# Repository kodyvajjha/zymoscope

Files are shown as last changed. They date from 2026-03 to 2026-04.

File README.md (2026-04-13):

# Zymoscope

An ESP32-based fermentation monitoring and control system with a real-time web dashboard.

## Overview

<p align="center">
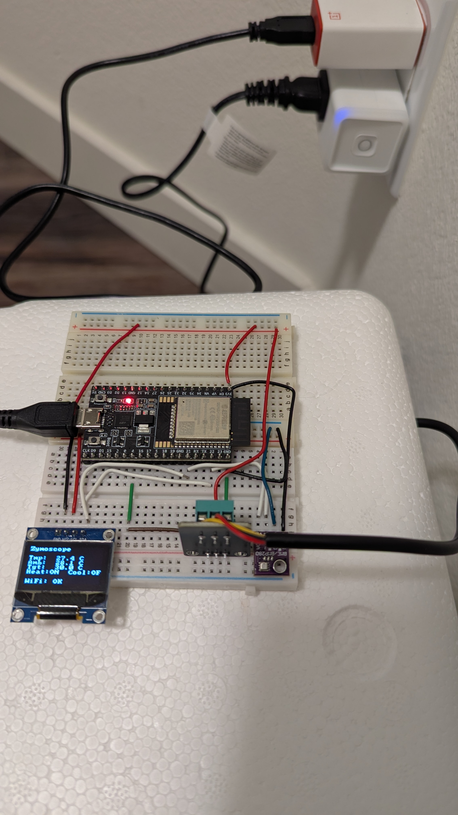
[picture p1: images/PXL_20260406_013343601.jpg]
Zymoscope prototype
  
  <br>
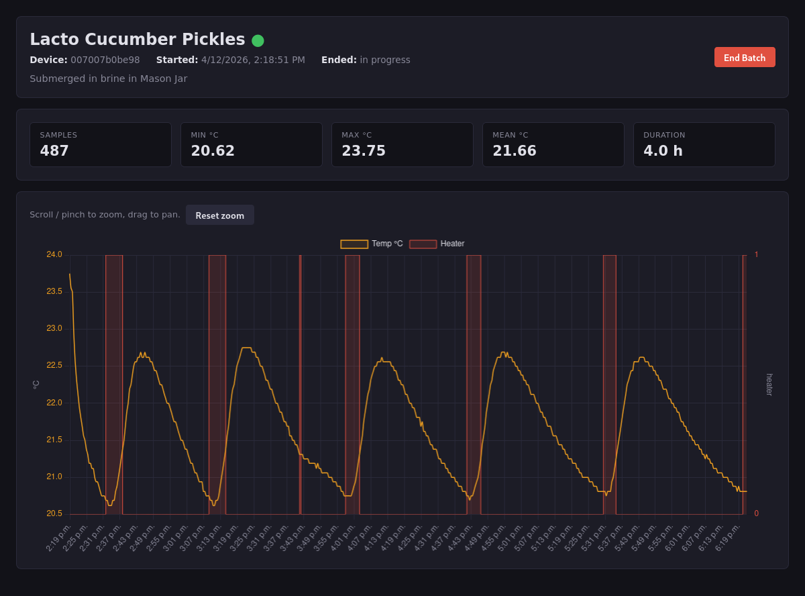
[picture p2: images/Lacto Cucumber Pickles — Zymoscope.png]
Dashboard screenshot — lacto cucumber pickles batch
  
</p>

Zymoscope monitors and controls fermentation environments using:

- **Temperature** sensing and PID control (DS18B20 probe + Kasa smart plug for heating/cooling)
- **Ambient climate** logging (BME280 — temperature, humidity, pressure)
- **Local display** on a 128x64 OLED for at-a-glance status
- **Wi-Fi telemetry** via MQTT to a self-hosted FastAPI + SQLite web dashboard
- **NVS-persisted setpoint** — the target temperature survives reboots; no dashboard needed to maintain control
- **Modular architecture** — ESP32 sensor nodes now, Raspberry Pi + camera later

Inspired by the [OpenAg FermentaBot](https://github.com/OpenAgricultureFoundation/fermentabot),
rebuilt from scratch with custom hardware, real sensor drivers, and a modern web frontend.

## What Can You Ferment With This?

Anything where temperature control and monitoring matter:

- **Koji** — *Aspergillus oryzae* needs 28–32 °C and high humidity for 40–48 hours.
  The PID holds your incubation chamber steady, the BME280 tracks humidity.
- **Natto** — *Bacillus subtilis* ferments at 38–42 °C for 22–24 hours.
  Tight temperature control is critical; even a few degrees off produces slimy,
  under-fermented beans.
- **Tempeh** — *Rhizopus oligosporus* sporulates at 30–32 °C over 24–48 hours.
  Too hot and the mold dies; too cold and it stalls. The dashboard shows you
  exactly when mycelium heat generation kicks in.
- **Beer / Cider / Mead** — ale yeast (18–22 °C), lager yeast (8–14 °C), or
  wild/mixed fermentation.
- **Kombucha** — SCOBY ferments best at 24–28 °C. Track progress over 7–14 days.
- **Hot Sauce** — lacto-fermented peppers at 20–24 °C.
- **Sauerkraut / Kimchi** — lacto-fermentation at 18–22 °C.
- **Yogurt / Kefir** — hold milk at 40–45 °C (yogurt) or 20–25 °C (kefir).
  The PID + smart plug keeps a heating pad at the right temperature overnight.
- **Bread / Sourdough** — proof at a controlled 24–28 °C. Bulk fermentation
  and final proof both benefit from consistent temperature.

The PID controller works with a seedling heat mat (via smart plug) for heating
and a small fan or mini fridge for cooling. One sensor node per vessel; run
multiple nodes reporting to the same dashboard.

## Architecture

```
ESP32 Sensor Node (per vessel)        Web App (laptop / Pi / server)
┌────────────────────────────┐        ┌─────────────────────────────┐
│ DS18B20 (1-Wire probe)     │  MQTT  │ FastAPI backend             │
│ BME280 (ambient)           │───────>│ SQLite storage              │
│ SSD1306 OLED (status)      │        │ WebSocket live push         │
│ PID temperature control    │<───────│ Chart.js dashboard          │
│ Kasa smart plug (via MQTT) │  cmds  │ Kasa plug control           │
└────────────────────────────┘        └─────────────────────────────┘
```

## Repository Layout

```
zymoscope/
├── firmware/                   # ESP-IDF v5.x firmware (C)
│   ├── main/
│   │   ├── app_main.c          # Entry point, FreeRTOS tasks
│   │   ├── sensor/
│   │   │   ├── ds18b20.c/h     # 1-Wire bit-bang, CRC-8, critical sections
│   │   │   ├── hx711.c/h       # 24-bit ADC bit-bang (optional)
│   │   │   └── bme280_i2c.c/h  # I2C driver, Bosch compensation formulas
│   │   ├── display/
│   │   │   └── oled.c/h        # SSD1306 128×64, built-in 8×8 font
│   │   ├── control/
│   │   │   └── pid.c/h         # PID with anti-windup, [-1,1] output
│   │   └── comms/
│   │       ├── wifi_sta.c/h    # Wi-Fi STA, auto-reconnect
│   │       └── mqtt_client.c/h # JSON telemetry + setpoint commands
│   ├── CMakeLists.txt
│   └── sdkconfig.defaults
├── dashboard/                  # Python web app
│   ├── zymoscope/
│   │   ├── server.py           # FastAPI routes + WebSocket
│   │   ├── db.py               # SQLite schema + queries (async)
│   │   ├── mqtt_sub.py         # MQTT subscriber thread
│   │   ├── smart_plug.py       # Kasa plug control + energy monitoring
│   │   └── config.py           # Environment-based settings
│   ├── templates/
│   │   └── index.html          # Dark-themed SPA, Chart.js live graphs
│   ├── mosquitto/
│   │   └── mosquitto.conf      # Local Mosquitto config
│   ├── docker-compose.yml      # Optional: Mosquitto + InfluxDB + Grafana
│   └── requirements.txt
├── hardware/                   # KiCad schematic + BOM
│   ├── zymoscope.kicad_pro
│   ├── zymoscope.kicad_sch
│   └── bom/
│       └── zymoscope-bom.csv
├── docs/
│   ├── design.md               # Full architecture + design rationale
│   ├── prototype-bom.md        # Ordering guide + wiring diagram
│   └── getting-started.md      # Step-by-step: order → build → ferment
├── .gitignore
├── LICENSE                     # GPL-3.0
└── README.md
```

## Prototype Build (~$40–55)

No custom PCB needed. Use an ESP32 dev board + breakout modules on a breadboard.

### Order from Mouser / DigiKey (~$20)

| Part | Mouser PN | Qty | ~Price |
|---|---|-----|---|
| ESP32-DevKitC-32E | 356-ESP32DEVKITC32E | 1 | $10.00 |
| DS18B20 waterproof stainless steel probe | 485-381 | 1 | $10.00 |
| 4.7 kΩ resistor (1/4W) | 603-MFR-25FBF52-4K7 | 1 | $0.10 |

### Order from Amazon (~$20–35)

| Part | Search Term | Qty | ~Price |
|---|---|-----|---|
| TP-Link Kasa KP115 smart plug | "TP-Link Kasa KP115" | 1 | $15–20 |
| BME280 I2C breakout | "BME280 breakout I2C" (NOT BMP280) | 1 | $3–5 |
| SSD1306 0.96" OLED 128×64 | "SSD1306 0.96 I2C OLED" | 1 | $3–4 |
| Half-size breadboard | "400 tie point breadboard" | 1 | $2–3 |
| Dupont jumper wires (M-M + M-F) | "dupont jumper wire kit" | 1 | $3–4 |
| Seedling heat mat | "seedling heat mat" | 1 | $8–12 |

### Optional extras

| Part | Search Term | Notes |
|---|---|---|
| HX711 + 5 kg load cell kit | "HX711 load cell kit 5kg" | For gravity estimation via weight loss |
| 2-ch 5V relay module | "2 channel 5V relay module" | For direct low-voltage DC control (fans, pumps) |

See [`docs/prototype-bom.md`](docs/prototype-bom.md) for detailed part notes and
[`docs/getting-started.md`](docs/getting-started.md) for the complete step-by-step
walkthrough from ordering parts to tracking your first fermentation.

## Quick Start

### Firmware

Requires [ESP-IDF v5.x](https://docs.espressif.com/projects/esp-idf/en/stable/esp32/get-started/).

```bash
# Set your Wi-Fi credentials
# Edit firmware/main/comms/wifi_sta.h: WIFI_SSID / WIFI_PASS

# Set your MQTT broker IP
# Edit firmware/main/app_main.c: MQTT_BROKER_URI

cd firmware/
source ~/esp/esp-idf/export.sh
idf.py set-target esp32
idf.py build
idf.py -p /dev/ttyUSB0 flash monitor
```

### MQTT Broker

```bash
# Install Mosquitto (Arch Linux)
sudo pacman -S mosquitto

# Run directly with the included config
mosquitto -c dashboard/mosquitto/mosquitto.conf
```

### Web Dashboard

```bash
cd dashboard/
pip install -r requirements.txt

# Set the Kasa plug IP (find with: kasa discover)
export KASA_HEATER_HOST=192.168.1.50

python -m zymoscope.server
# Open http://localhost:8000
```

The dashboard shows per-device cards with live temperature, ambient conditions,
plug states, and 24-hour trend charts. Use the "Target Temperature" control in
the sidebar to change the PID setpoint. Data persists in SQLite.

### Set Target Temperature

From the dashboard sidebar, or via curl:

```bash
curl -X POST http://localhost:8000/api/cmd/YOUR_DEVICE_ID \
  -H "Content-Type: application/json" \
  -d '{"setpoint": 25.0}'
```

The setpoint is saved to the ESP32's NVS flash — it persists across reboots
and works even without the dashboard running.

### Docker Stack (optional)

If you want Mosquitto + InfluxDB + Grafana alongside the web app:

```bash
cd dashboard/
cp .env.example .env   # edit secrets
docker compose up -d
```

## Wiring

```
ESP32 Pin     Peripheral
─────────     ──────────────────────────────────────────
GPIO 4        DS18B20 DATA + 4.7 kΩ pull-up to 3.3V
GPIO 21       I2C SDA (BME280 @ 0x76 + OLED @ 0x3C)
GPIO 22       I2C SCL (BME280 + OLED)
3.3V          DS18B20 VCC, BME280 VCC, OLED VCC
GND           Common ground
```

**Optional (if using HX711 / relay instead of smart plug):**

```
GPIO 18       HX711 SCK
GPIO 19       HX711 DOUT
GPIO 25       Relay IN1 (heater)
GPIO 26       Relay IN2 (cooler)
5V (VIN)      Relay module VCC, HX711 VCC
```

## OLED Display

```
Zymoscope

Tmp:  24.9 C      ← DS18B20 probe (-- if disconnected)
Amb:  22.3 C      ← BME280 ambient
Tgt:  20.0 C      ← PID setpoint
Heat:OFF Cool:OFF ← Kasa plug / relay state

WiFi: OK
```

## MQTT Topics

```
zymoscope/<mac>/telemetry    # JSON, published every 30 s
zymoscope/<mac>/cmd          # Subscribe: {"setpoint": 20.0}
zymoscope/<mac>/status       # LWT: "online" / "offline"
```

## Roadmap

- [x] ESP32 sensor node firmware (DS18B20, BME280, OLED, PID, MQTT)
- [x] FastAPI web dashboard with live charts
- [x] Kasa smart plug integration (heater/cooler control + energy monitoring)
- [x] NVS-persisted setpoint (survives reboots)
- [x] Critical sections for reliable 1-Wire reads on noisy power rails
- [ ] Raspberry Pi integration + camera module (krausen tracking)
- [ ] pH probe support (analog front-end)
- [ ] OTA firmware updates
- [ ] Fermentation profile automation (diacetyl rest, crash cool)
- [ ] Custom 2-layer PCB (KiCad, JLCPCB-ready)
- [ ] 3D-printable enclosure (OpenSCAD)

## License

This project is licensed under the **GNU General Public License v3.0**.
See [LICENSE](LICENSE) for details.

Hardware design files are additionally released under
**CERN Open Hardware Licence v2 – Strongly Reciprocal (CERN-OHL-S-2.0)**.

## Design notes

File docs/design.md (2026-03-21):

# Zymoscope — Design Document

## 1. Goals and Constraints

| Goal | Rationale |
|---|---|
| Self-hosted telemetry | No cloud dependency for reliability |
| ±0.1 °C temperature accuracy | Tight lager fermentation window |
| BLE tilt sensor support | Passive gravity readings without opening vessel |
| Sub-$30 BOM per unit | Hobbyist replicability |
| DIN-rail enclosure | Clean brewery panel mounting |

## 2. System Architecture

```
┌─────────────────────────────────────────────────────┐
│  Fermentation Vessel                                │
│  ┌──────────┐   ┌──────────┐   ┌────────────────┐  │
│  │ DS18B20  │   │  Tilt    │   │ CO2 pressure   │  │
│  │ (1-Wire) │   │ (BLE RX) │   │ sensor (I²C)   │  │
│  └────┬─────┘   └────┬─────┘   └───────┬────────┘  │
└───────┼──────────────┼─────────────────┼────────────┘
        │              │                 │
┌───────▼──────────────▼─────────────────▼────────────┐
│  Zymoscope PCB                                      │
│  ┌────────────────────────────────────────────────┐ │
│  │  ESP32-WROOM-32E                               │ │
│  │  ┌──────────┐  ┌──────────┐  ┌─────────────┐  │ │
│  │  │ 1-Wire   │  │  BLE     │  │  I²C master │  │ │
│  │  │ driver   │  │  scanner │  │             │  │ │
│  │  └────┬─────┘  └──────────┘  └──────┬──────┘  │ │
│  │       │   ┌─────────────────────────┘         │ │
│  │       └───►  Sensor fusion / state machine     │ │
│  │             │                                  │ │
│  │             ▼                                  │ │
│  │         MQTT publish ──► Wi-Fi ──► broker      │ │
│  │         OLED update                            │ │
│  │         Relay control (GPIO)                   │ │
│  └────────────────────────────────────────────────┘ │
│  ┌────────────┐  ┌───────────────────────────────┐  │
│  │ AMS1117    │  │ Relay ×2 (heater / cooler)    │  │
│  │ 3.3V LDO   │  │ 5V coil, opto-isolated        │  │
│  └────────────┘  └───────────────────────────────┘  │
└─────────────────────────────────────────────────────┘
                        │ MQTT
                        ▼
┌─────────────────────────────────────────────────────┐
│  Self-hosted stack (Raspberry Pi / VM)              │
│  Mosquitto ──► Telegraf ──► InfluxDB ──► Grafana    │
│                                 └──► Alert webhooks │
└─────────────────────────────────────────────────────┘
```

## 3. Hardware Design

### 3.1 MCU Selection — ESP32-WROOM-32E

- Dual-core Xtensa LX6 @ 240 MHz; plenty of headroom for BLE scanning + MQTT
- Integrated Wi-Fi (802.11 b/g/n) + BLE 4.2
- 4 MB flash; 520 KB SRAM
- Wide supply range (3.0–3.6 V); efficient at 80 MHz for always-on monitoring

### 3.2 Power Supply

- Input: 5 V DC barrel jack (2.1 mm center-positive)
- 3.3 V rail: AMS1117-3.3 LDO, 800 mA max
- Relay coils driven from 5 V rail directly (before LDO)
- ESP32 EN pin pulled high via 10 kΩ; boot strapping resistors per Espressif ref design

### 3.3 Temperature Sensing — DS18B20

- Parasitic power mode, 1-Wire on GPIO4
- 4.7 kΩ pull-up to 3.3 V
- 12-bit resolution → 0.0625 °C step; conversion time 750 ms max
- Up to 4 probes on one bus (vessel, ambient, cold side, hot side)

### 3.4 Display — SSD1306 128×64 OLED

- I²C at 0x3C, 400 kHz fast mode
- Shows: current temp, setpoint, gravity estimate, elapsed days, Wi-Fi status
- GPIO21 = SDA, GPIO22 = SCL

### 3.5 Relay Outputs

- Two SPDT relays, 10 A / 250 VAC contacts
- Opto-isolated driver (PC817); GPIO driven via NPN transistor (2N2222)
- Flyback diode on coil (1N4148)
- Output 1 — Heater (heating pad / heat wrap)
- Output 2 — Cooler (mini fridge or Peltier module)

### 3.6 Connectors

| Connector | Type | Signals |
|---|---|---|
| J1 | 2-pin 5.08 mm screw terminal | 5 V in, GND |
| J2 | 3-pin 3.81 mm screw terminal | 1-Wire (DATA, GND, VCC) |
| J3 | 2-pin 5.08 mm screw terminal | Relay 1 NO/COM |
| J4 | 2-pin 5.08 mm screw terminal | Relay 2 NO/COM |
| J5 | 4-pin 2.54 mm header | UART0 (TX, RX, GND, 3V3) for flashing |

## 4. Firmware Architecture

```
main/
├── app_main.c          Entry point, task creation
├── sensor/
│   ├── ds18b20.c       1-Wire driver
│   └── tilt_ble.c      BLE passive scanner (iBeacon / Tilt UUID)
├── control/
│   └── pid.c           Simple PID for temperature setpoint
├── comms/
│   ├── mqtt_client.c   Publish telemetry JSON
│   └── wifi_sta.c      Wi-Fi init + reconnect
├── display/
│   └── oled.c          SSD1306 I²C driver + layout
└── config/
    └── nvs_config.c    Persist setpoint + credentials to NVS
```

### 4.1 MQTT Topic Schema

```
zymoscope/<device_id>/telemetry   JSON, published every 30 s
zymoscope/<device_id>/cmd         Subscribe for setpoint / relay override
zymoscope/<device_id>/status      LWT "offline" / "online"
```

Telemetry payload example:
```json
{
  "ts": 1710000000,
  "temp_c": [20.1, 19.8],
  "gravity_sg": 1.048,
  "relay": [0, 1],
  "rssi": -62,
  "uptime_s": 86400
}
```

## 5. Dashboard Stack

| Service | Image | Port |
|---|---|---|
| Mosquitto | eclipse-mosquitto:2 | 1883, 8883 |
| Telegraf | telegraf:1.30 | — |
| InfluxDB | influxdb:2.7 | 8086 |
| Grafana | grafana/grafana-oss:10.4 | 3000 |

Grafana dashboards are provisioned via YAML in `dashboard/grafana/provisioning/`.

## 6. Open Items / Future Work

- [ ] Add flow meter for sparge water (v3)
- [ ] OTA firmware update via HTTPS
- [ ] PCB revision: add TVS diodes on relay output terminals
- [ ] Evaluate CO2 volume measurement via pressure + temp logging
- [ ] Mobile-friendly Grafana layout

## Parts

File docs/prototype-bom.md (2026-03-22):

# Zymoscope v2 — Prototype Build Guide

## Overview

This is the **minimum viable prototype**: an ESP32 dev board + breakout sensor
modules wired on a protoboard. No custom PCB needed. Total cost: **~$45–55** (or ~$60–75 with an optional Kasa smart plug)
depending on supplier.

The goal is to validate the sensor pipeline, firmware, and web app before
committing to a PCB revision.

---

## Parts List

### Core (order from Mouser or DigiKey)

| # | Part | Mouser PN | Qty | ~Price | Notes |
|---|---|---|-----|---|---|
| 1 | **ESP32-DevKitC-32E** | 356-ESP32DEVKITC32E | 1 | $10.00 | USB-C variant preferred. Any ESP32 dev board with GPIO breakout works. |
| 2 | **DS18B20 waterproof stainless steel probe** (1m cable) | 485-381 | 1 | $10.00 | Pre-wired stainless steel probe — required for liquid immersion. |
| 3 | **4.7 kΩ resistor** (1/4W axial) | 603-MFR-25FBF52-4K7 | 1 | $0.10 | 1-Wire pull-up. Grab a 5-pack. |
| 4 | **10 kΩ resistor** (1/4W axial) | 603-MFR-25FBF52-10K | 2 | $0.10 | Pull-ups. Grab a 5-pack. |

**Mouser subtotal: ~$20**

### Breakout Modules (cheaper on Amazon or AliExpress)

These are commodity breakout boards. Mouser sells some of them but at 3–5x the
price. Amazon 2-day shipping is the sweet spot for prototyping.

| # | Part | Where to Buy | Qty | ~Price | Notes |
|---|---|---|-----|---|---|
| 5 | **HX711 + 5 kg load cell kit** | Amazon / AliExpress | 1 | $8–10 | Search "HX711 load cell kit 5kg". Comes with the HX711 breakout board + aluminum bar load cell + wires. This is your gravity sensor. |
| 6 | **BME280 breakout** (I2C, 3.3V) | Amazon / AliExpress | 1 | $3–5 | Search "BME280 breakout I2C". **Make sure it's a BME280, not BMP280** — the BME has humidity. 4-pin (VCC, GND, SCL, SDA). |
| 7 | **SSD1306 0.96" OLED** (I2C, 128×64) | Amazon / AliExpress | 1 | $3–4 | Search "SSD1306 0.96 I2C OLED". 4-pin version (VCC, GND, SCL, SDA). White or blue, doesn't matter. |
| 8 | **2-channel 5V relay module** (opto-isolated) | Amazon | 1 | $4–5 | Search "2 channel 5V relay module optocoupler". Has screw terminals for AC loads. High/low trigger selectable. |
| 9 | **Half-size breadboard** (400 tie points) | Amazon | 1 | $2–3 | Or a 7×9 cm solderable protoboard if you want something permanent. |
| 10 | **Dupont jumper wires** (M-M, M-F) | Amazon | 1 pack | $3–4 | 40-pin ribbon, get both male-male and male-female. |
| 11 | **Micro USB or USB-C cable** | — | 1 | $0 | You probably have one. Powers the ESP32 + provides serial for flashing. |

### Optional: Smart Plug (recommended for heater/cooler control)

| # | Part | Where to Buy | Qty | ~Price | Notes |
|---|---|---|-----|---|---|
| 12 | **TP-Link Kasa KP115** smart plug | Amazon | 1 | $15–20 | Search "TP-Link Kasa KP115". Has energy monitoring (power, voltage, current). Controlled locally via python-kasa — no cloud required. Plug your seedling heat mat or space heater into this instead of wiring mains through the relay module. KP125, HS110, or similar Kasa plugs also work. |

**Amazon subtotal: ~$25–30** (or ~$40–50 with smart plug)

---

## What You Probably Already Have

- A laptop with USB (for flashing firmware)
- A 5V USB power supply / phone charger (1A+ is fine for prototyping)
- Something to ferment (beer, kombucha, whatever — or just a jar of warm water to test with)

## What You Do NOT Need Yet

- Custom PCB (that's phase 2, after we validate the prototype)
- Raspberry Pi (the web app runs on your laptop for now)
- pH sensor (adds analog complexity — save for v2.1)
- Barrel jack / DIN rail enclosure (prototype lives on the bench)
- Pi Camera (future phase)

---

## Wiring Guide

Once parts arrive, wire it up like this:

```
ESP32 DevKit Pin    →   Peripheral
──────────────────────────────────────────────────
GPIO 4              →   DS18B20 DATA (yellow wire)
                        + 4.7 kΩ pull-up to 3.3V
3.3V                →   DS18B20 VCC (red wire)
GND                 →   DS18B20 GND (black wire)

GPIO 18             →   HX711 SCK
GPIO 19             →   HX711 DT (DOUT)
3.3V                →   HX711 VCC
GND                 →   HX711 GND
                        Load cell wires → HX711 E+/E-/A+/A-
                        (red→E+, black→E-, white→A+, green→A-)

GPIO 21 (SDA)       →   BME280 SDA  +  OLED SDA  (shared I2C bus)
GPIO 22 (SCL)       →   BME280 SCL  +  OLED SCL  (shared I2C bus)
3.3V                →   BME280 VCC  +  OLED VCC
GND                 →   BME280 GND  +  OLED GND
                        (BME280 default addr: 0x76)
                        (SSD1306 default addr: 0x3C)

GPIO 25             →   Relay module IN1 (heater)
GPIO 26             →   Relay module IN2 (cooler)
5V (VIN pin)        →   Relay module VCC
GND                 →   Relay module GND
                        (Set relay jumper to LOW-trigger if available)
```

### Load Cell Mounting (for gravity estimation)

For prototyping, the simplest setup:

1. Screw the load cell to a flat board (wood or acrylic) at one end
2. Attach a small platform on the free end (zip-tie a flat piece)
3. Place your fermentation vessel on the platform
4. Tare after placing the full vessel — you're measuring *weight loss* from CO2 off-gassing

A 5 kg cell works for vessels up to ~5 kg total (≈1 gallon batch + container).
For 5-gallon batches, get a 20 kg load cell instead (~$2 more).

---

## Order Checklist

Copy-paste for ordering:

```
Mouser / DigiKey:
  [ ] ESP32-DevKitC-32E (or any ESP32 dev board)     ×1
  [ ] DS18B20 waterproof probe (pre-wired, 1m)        ×1
  [ ] 4.7 kΩ 1/4W resistor (5-pack)                   ×1
  [ ] 10 kΩ 1/4W resistor (5-pack)                     ×1

Amazon:
  [ ] HX711 + 5 kg load cell kit                       ×1
  [ ] BME280 I2C breakout (NOT BMP280)                  ×1
  [ ] SSD1306 0.96" OLED I2C 128×64                     ×1
  [ ] 2-channel 5V relay module (opto-isolated)         ×1
  [ ] Half-size breadboard (or 7×9 cm protoboard)       ×1
  [ ] Dupont jumper wires (M-M + M-F, 40-pin)          ×1

Optional:
  [ ] TP-Link Kasa KP115 smart plug (for heater)       ×1

Total: ~$45–55 (or ~$60–75 with smart plug)
```

---

## Next Steps After Parts Arrive

1. Wire everything per the diagram above
2. Flash the firmware: `cd firmware/ && idf.py build flash monitor`
3. Start the web app: `cd dashboard/ && python -m zymoscope.server`
4. Open `http://localhost:8080` — you should see live sensor data
5. Calibrate the load cell with a known weight
6. Stick the temp probe in your vessel and start a batch

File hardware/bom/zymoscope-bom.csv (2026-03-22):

Reference | Quantity | Value | Footprint | MPN | Supplier | Supplier PN | Unit Price (USD) | Notes
U1 | 1 | ESP32-WROOM-32E | RF_Module:ESP32-WROOM-32 | ESP32-WROOM-32E-N4 | Mouser | 356-ESP32WROOM32EN4 | 3.50 | 4 MB flash variant
U2 | 1 | AMS1117-3.3 | Package_TO_SOT_SMD:SOT-223-3_TabPin2 | AMS1117-3.3 | LCSC | C6186 | 0.15 | 800 mA LDO
U3 | 1 | SSD1306 OLED 128x64 | Connector_PinHeader_2.54mm:PinHeader_1x04_P2.54mm_Vertical | SSD1306 0.96" | AliExpress | — | 1.20 | I2C | 4-pin breakout
DS1 | 1 | DS18B20 | — | DS18B20+ | Mouser | 485-381 | 10.00 | Waterproof stainless steel probe (1m cable)
K1 | 1 | Relay 5V SPDT 10A | Relay_THT:Relay_SPDT_Omron_G5LE | G5LE-14-DC5 | Mouser | 653-G5LE-14DC5 | 1.85 | 5V coil
K2 | 1 | Relay 5V SPDT 10A | Relay_THT:Relay_SPDT_Omron_G5LE | G5LE-14-DC5 | Mouser | 653-G5LE-14DC5 | 1.85 | 5V coil
Q1 | 1 | 2N2222A | Package_TO_SOT_THT:TO-92_Inline | 2N2222A | Mouser | 512-2N2222A | 0.25 | Relay driver NPN (K1)
Q2 | 1 | 2N2222A | Package_TO_SOT_THT:TO-92_Inline | 2N2222A | Mouser | 512-2N2222A | 0.25 | Relay driver NPN (K2)
OC1 | 1 | PC817 | Package_DIP:DIP-4_W7.62mm | PC817C | LCSC | C66880 | 0.08 | Opto-isolator (K1 drive)
OC2 | 1 | PC817 | Package_DIP:DIP-4_W7.62mm | PC817C | LCSC | C66880 | 0.08 | Opto-isolator (K2 drive)
D1 | 1 | 1N4148 | Diode_THT:D_DO-35_SOD27_P7.62mm_Horizontal | 1N4148 | Mouser | 512-1N4148 | 0.05 | Flyback diode K1
D2 | 1 | 1N4148 | Diode_THT:D_DO-35_SOD27_P7.62mm_Horizontal | 1N4148 | Mouser | 512-1N4148 | 0.05 | Flyback diode K2
R1 | 1 | 4.7k | Resistor_THT:R_Axial_DIN0207_L6.3mm_D2.5mm_P10.16mm_Horizontal | — | — | — | 0.02 | 1-Wire pull-up
R2 | 1 | 10k | Resistor_THT:R_Axial_DIN0207_L6.3mm_D2.5mm_P10.16mm_Horizontal | — | — | — | 0.02 | ESP32 EN pull-up
R3 | 1 | 1k | Resistor_THT:R_Axial_DIN0207_L6.3mm_D2.5mm_P10.16mm_Horizontal | — | — | — | 0.02 | Q1 base resistor
R4 | 1 | 1k | Resistor_THT:R_Axial_DIN0207_L6.3mm_D2.5mm_P10.16mm_Horizontal | — | — | — | 0.02 | Q2 base resistor
R5 | 1 | 10k | Resistor_THT:R_Axial_DIN0207_L6.3mm_D2.5mm_P10.16mm_Horizontal | — | — | — | 0.02 | GPIO0 pull-up (boot)
C1 | 1 | 100nF | Capacitor_SMD:C_0402_1005Metric | — | — | — | 0.02 | 3.3V bypass (near U2)
C2 | 1 | 100nF | Capacitor_SMD:C_0402_1005Metric | — | — | — | 0.02 | 3.3V bypass (near U1)
C3 | 1 | 10uF 10V | Capacitor_THT:C_Radial_D5.0mm_H11.0mm_P2.00mm | — | — | — | 0.10 | 3.3V bulk
C4 | 1 | 100uF 10V | Capacitor_THT:C_Radial_D8.0mm_H11.5mm_P3.50mm | — | — | — | 0.15 | 5V bulk
J1 | 1 | Barrel Jack 2.1mm | Connector_BarrelJack:BarrelJack_Wuerth_6941xx301002 | — | Mouser | — | 0.80 | 5V DC input
J2 | 1 | Screw Terminal 3-pin 3.81mm | TerminalBlock_Phoenix:MKDS_1 | 5_3-5.08 | — | — | — | 0.60 | 1-Wire probe connector
J3 | 1 | Screw Terminal 2-pin 5.08mm | TerminalBlock_Phoenix:MKDS_1 | 5_2-5.08 | — | — | — | 0.45 | Relay 1 output
J4 | 1 | Screw Terminal 2-pin 5.08mm | TerminalBlock_Phoenix:MKDS_1 | 5_2-5.08 | — | — | — | 0.45 | Relay 2 output
J5 | 1 | Pin Header 4-pin 2.54mm | Connector_PinHeader_2.54mm:PinHeader_1x04_P2.54mm_Vertical | — | — | — | 0.20 | UART/prog header
PCB | 1 | Custom 2-layer PCB | — | — | JLCPCB | — | 8.00 | 10 pcs @ $8 min order
Enclosure | 1 | DIN rail enclosure | — | — | AliExpress | — | 4.50 | 45 mm DIN rail snap
 |  |  |  |  |  | Estimated total (1 unit): | $26.30

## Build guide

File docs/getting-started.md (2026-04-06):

# Zymoscope v2 — Getting Started (Step by Step)

Everything from ordering parts to watching your first fermentation curve on
the dashboard.

---

## Step 1: Order Parts

Place two orders. The Mouser/DigiKey parts are precision components with
exact part numbers. The Amazon parts are generic breakout boards — any
equivalent works.

### Mouser order (~$20, ships in 1–2 days)

Go to [mouser.com](https://www.mouser.com). Add each part number to your cart:

| Part | Mouser Part Number | Qty |
|---|---|-----|
| ESP32-DevKitC-32E dev board | **356-ESP32DEVKITC32E** | 1 |
| DS18B20 temperature probe | **485-381** | 1 |
| 4.7 kΩ resistor, 1/4W | **603-MFR-25FBF52-4K7** | 5 (pack) |

> **Note:** This is the waterproof stainless steel probe version with
> pre-wired leads (red/yellow/black). Required for liquid immersion.

### Amazon order (~$25–35, ships in 1–2 days with Prime)

Search for each item. These are commodity parts — any seller works.

| Part | What to Search | Qty | Tips |
|---|---|-----|---|
| TP-Link Kasa KP115 smart plug | "TP-Link Kasa KP115" | 1 | The KP115 includes energy monitoring (power/voltage/current shown on the dashboard). KP125 or HS110 also work. ~$15–20. |
| BME280 breakout | "BME280 breakout board I2C 3.3V" | 1 | **IMPORTANT: verify it says BME280, not BMP280.** The BMP lacks the humidity sensor. Should be a small purple or blue board with 4 pins (VCC, GND, SCL, SDA). **Solder the header pins** — resting the board on unsoldered pins causes noise that corrupts the DS18B20. |
| SSD1306 OLED | "SSD1306 0.96 inch OLED I2C 128x64" | 1 | 4-pin I2C version (not SPI). Color doesn't matter — white or blue. **Solder header pins.** |
| Seedling heat mat | "seedling heat mat" | 1 | Plugs into the Kasa smart plug. The PID controller turns it on/off to maintain target temperature. |
| Breadboard | "solderless breadboard 830 point" or "400 tie point breadboard" | 1 | Full-size (830 point) is easiest for the ESP32-DevKitC. Half-size works if you run power/ground off-board. |
| Jumper wires | "dupont jumper wire kit male male female" | 1 | 40-pin ribbon. Get a pack with both male-male and male-female wires. |

### What you probably already have

- USB-A to Micro USB or USB-C cable (for the ESP32)
- A laptop (Linux, macOS, or Windows — for flashing and running the dashboard)
- A 5V USB power supply or phone charger (1A+)

### Optional extras

| Part | What to Search | Notes |
|---|---|---|
| HX711 + 5 kg load cell kit | "HX711 load cell kit 5kg" | For gravity estimation via weight loss. Not needed for basic temperature control. |
| 2-channel relay module | "2 channel 5V relay module optocoupler" | For direct low-voltage DC control (fans, pumps, LED strips). Not needed if using the Kasa smart plug. |
| 10 kΩ resistor, 1/4W | 603-MFR-25FBF52-10K (Mouser) | Only needed if using the HX711. |

### Total: ~$40–55

---

## Step 2: Install Software (while you wait for parts)

### 2a: Install ESP-IDF (firmware toolchain)

Follow Espressif's official guide for your OS:
https://docs.espressif.com/projects/esp-idf/en/stable/esp32/get-started/

**Linux (quick version):**

```bash
sudo apt install git wget flex bison gperf python3 python3-venv \
  cmake ninja-build ccache libffi-dev libssl-dev dfu-util libusb-1.0-0

mkdir -p ~/esp
cd ~/esp
git clone --recursive https://github.com/espressif/esp-idf.git -b v5.2.2
cd esp-idf
./install.sh esp32
source export.sh    # run this in every new terminal, or add to .bashrc
```

**Arch Linux:**

```bash
sudo pacman -S git wget flex bison gperf python cmake ninja ccache \
  libffi openssl dfu-util libusb

mkdir -p ~/esp && cd ~/esp
git clone --recursive https://github.com/espressif/esp-idf.git -b v5.2.2
cd esp-idf
./install.sh esp32
source export.sh
```

**macOS:**

```bash
brew install cmake ninja dfu-util python3
mkdir -p ~/esp && cd ~/esp
git clone --recursive https://github.com/espressif/esp-idf.git -b v5.2.2
cd esp-idf
./install.sh esp32
source export.sh
```

Verify it works:

```bash
idf.py --version
# Should print something like: ESP-IDF v5.2.2
```

### 2b: Install Python dependencies (web dashboard)

```bash
cd /path/to/zymoscope/dashboard
python3 -m venv .venv
source .venv/bin/activate
pip install -r requirements.txt
```

### 2c: Install an MQTT broker

The web app and ESP32 communicate via MQTT. You need a broker running
somewhere on your network.

**Option A — Run directly (simplest):**

```bash
# Install
sudo pacman -S mosquitto          # Arch
sudo apt install mosquitto         # Debian/Ubuntu
brew install mosquitto             # macOS

# Run with the included config
mosquitto -c /path/to/zymoscope/dashboard/mosquitto/mosquitto.conf
```

**Option B — Docker:**

```bash
docker run -d --name mosquitto \
  -p 1883:1883 \
  eclipse-mosquitto:2 \
  mosquitto -c /mosquitto-no-auth.conf
```

**Option C — Use the included Docker Compose stack:**

```bash
cd dashboard/
cp .env.example .env
docker compose up -d mosquitto
```

Verify the broker is running:

```bash
# In one terminal:
mosquitto_sub -h localhost -t "test/#"

# In another:
mosquitto_pub -h localhost -t "test/hello" -m "it works"
# You should see "it works" appear in the first terminal
```

### 2d: Set up the Kasa smart plug

1. Plug in the KP115 and set it up on your Wi-Fi using the Kasa app (one-time)
2. Find its IP address:

```bash
kasa discover
```

Note the IP address — you'll need it when starting the dashboard.

---

## Step 3: Wire the Hardware

Unpack everything and set it up on the breadboard. Work through one
peripheral at a time — it's easier to debug that way.

> **Important:** Solder header pins onto the BME280 and OLED modules before
> wiring. Resting them on unsoldered pins causes intermittent contact that
> corrupts sensor readings and produces CRC errors.

### 3a: Place the ESP32 dev board

Straddle it across the center channel of the breadboard so the pins go
into both sides. The USB port should face outward for easy access.

### 3b: Wire the DS18B20 temperature probe

```
DS18B20 wire color    →   ESP32
──────────────────────────────────
Red (VCC)             →   3.3V
Black (GND)           →   GND
Yellow (DATA)         →   GPIO 4

Also: place the 4.7 kΩ resistor between GPIO 4 and 3.3V
      (this is the 1-Wire pull-up — required)
```

### 3c: Wire the BME280 (ambient sensor)

```
BME280 pin        →   ESP32
──────────────────────────────────
VCC               →   3.3V
GND               →   GND
SDA               →   GPIO 21
SCL               →   GPIO 22
```

> **Tip:** Run separate power jumpers from the ESP32 3.3V pin to each sensor
> rather than daisy-chaining them on one breadboard power rail. This reduces
> noise coupling between the BME280 and DS18B20.

### 3d: Wire the SSD1306 OLED

Shares the same I2C bus as the BME280 — wire to the same GPIO 21 / 22:

```
OLED pin          →   ESP32
──────────────────────────────────
VCC               →   3.3V
GND               →   GND
SDA               →   GPIO 21  (same wire row as BME280 SDA)
SCL               →   GPIO 22  (same wire row as BME280 SCL)
```

Both devices coexist on the same bus (BME280 @ address 0x76, OLED @ 0x3C).

### 3e: Set up the Kasa smart plug

1. Plug the seedling heat mat into the Kasa smart plug
2. Plug the smart plug into the wall outlet
3. The dashboard controls the plug over Wi-Fi — no wiring to the ESP32

### 3f: Double-check

Before powering on:

- [ ] All GND wires go to the same ground rail
- [ ] 3.3V is not shorted to anything it shouldn't be
- [ ] The 4.7 kΩ resistor is between GPIO 4 and 3.3V
- [ ] I2C SDA/SCL wires from BME280 and OLED both go to GPIO 21/22
- [ ] BME280 and OLED header pins are **soldered**, not just resting
- [ ] No loose jumper wires touching things they shouldn't

---

## Step 4: Configure and Flash the Firmware

### 4a: Set your Wi-Fi credentials

Edit `firmware/main/comms/wifi_sta.h` and change the defaults:

```c
#ifndef WIFI_SSID
#define WIFI_SSID "YourWiFiName"       // <── change this
#endif

#ifndef WIFI_PASS
#define WIFI_PASS "YourWiFiPassword"   // <── change this
#endif
```

### 4b: Set your MQTT broker address

Find the IP of the machine running Mosquitto:

```bash
# Linux
ip addr show | grep 'inet 10\.\|inet 192\.'

# macOS
ipconfig getifaddr en0
```

Edit `firmware/main/app_main.c` and change the broker URI:

```c
#ifndef MQTT_BROKER_URI
#define MQTT_BROKER_URI "mqtt://192.168.1.100:1883"  // <── your broker IP
#endif
```

### 4c: Build and flash

Plug the ESP32 into your laptop via USB.

```bash
# Make sure ESP-IDF is sourced
source ~/esp/esp-idf/export.sh

cd /path/to/zymoscope/firmware

idf.py set-target esp32
idf.py build
idf.py -p /dev/ttyUSB0 flash monitor
```

> **Port notes:**
> - Linux: usually `/dev/ttyUSB0` or `/dev/ttyACM0`
> - macOS: `/dev/cu.usbserial-*` or `/dev/cu.SLAB_USBtoUART`
> - If permission denied on Linux: `sudo usermod -aG dialout $USER` then log out/in

You should see log output like:

```
I (520) zymoscope: Zymoscope v2 starting...
I (530) zymoscope: Device MAC: AA:BB:CC:DD:EE:FF
I (845) wifi_sta: Connecting...
I (935) wifi:connected with YourWiFiName
I (875) bme280: BME280 initialised (addr=0x76, I2C port 0)
I (985) oled: SSD1306 128x64 OLED initialised (addr=0x3C)
I (1015) ds18b20: Found sensor 1: 2831A37B00000085
I (2655) mqtt: Connected to broker
```

The OLED should light up showing temperature, target setpoint, and connection
status. Press `Ctrl+]` to exit the serial monitor.

---

## Step 5: Start the Web Dashboard

### 5a: Start Mosquitto (if not already running)

```bash
mosquitto -c /path/to/zymoscope/dashboard/mosquitto/mosquitto.conf
```

### 5b: Start the dashboard

In a new terminal:

```bash
cd /path/to/zymoscope/dashboard
source .venv/bin/activate

# Set the Kasa plug IP
export KASA_HEATER_HOST=192.168.1.50    # your plug's IP from kasa discover

# Optional: for a cooler plug too
# export KASA_COOLER_HOST=192.168.1.51

python -m zymoscope.server
```

Open **http://localhost:8000** in your browser.

You should see:
- A dark-themed dashboard
- A card for your ESP32 device (identified by its MAC address)
- Live temperature and ambient readings
- Heater/cooler state indicators
- A line chart updating every 30 seconds
- "Target Temperature" control in the sidebar

If you don't see a device card, check:
1. Is the ESP32 connected to Wi-Fi? (check serial monitor output)
2. Is the MQTT broker running?
3. Is the ESP32's `MQTT_BROKER_URI` pointing to the right IP?

---

## Step 6: Set the Target Temperature

The PID controller maintains a target temperature by toggling the Kasa smart
plug (heater) on and off. The default is 20.0 °C.

### From the dashboard

Use the "Target Temperature" input in the sidebar. Enter a value and click
**Set**. The OLED will update to show the new target.

### From the command line

```bash
# Replace the device ID with yours (shown in serial monitor or dashboard)
curl -X POST http://localhost:8000/api/cmd/aabbccddeeff \
  -H "Content-Type: application/json" \
  -d '{"setpoint": 25.0}'
```

### Via MQTT directly

```bash
mosquitto_pub -h localhost \
  -t "zymoscope/aabbccddeeff/cmd" \
  -m '{"setpoint": 25.0}'
```

The setpoint is saved to the ESP32's NVS (non-volatile storage). It persists
across reboots — you can unplug the laptop and the ESP32 keeps controlling
temperature at the last setpoint.

---

## Step 7: Start a Fermentation

### 7a: Prepare your vessel

Whatever you're fermenting — beer, kombucha, cider, mead, hot sauce, etc.
A 1-gallon glass jug or a small fermentation bucket works well.

### 7b: Position the sensors

1. Dip the DS18B20 probe into the liquid (use the airlock hole or tape it
   to the outside of the vessel for external temp)
2. Place the seedling heat mat under or around the vessel, plugged into the
   Kasa smart plug
3. The BME280 stays on the breadboard — it reads ambient room conditions
4. The OLED sits on the breadboard — it shows live status

### 7c: Power on

1. Plug in the ESP32 via USB
2. Wait for the boot sequence
3. Check the serial monitor to confirm readings look sane
4. Check the web dashboard — you should see the device card with live data

### 7d: Walk away

The system now runs autonomously:

- Temperature is logged every 5 seconds
- Telemetry is published to MQTT every 30 seconds
- The PID controller toggles the heat mat via the Kasa plug to maintain
  your target temperature
- The web dashboard stores and plots everything (when running)
- The ESP32 + Kasa plug work independently of the dashboard

Check in on the dashboard periodically, or just glance at the OLED.

---

## Troubleshooting

| Problem | Check |
|---|---|
| ESP32 won't flash | Correct USB port? Try holding BOOT button while flashing. Run `ls /dev/tty*` to find the port. |
| No temperature readings | Is the 4.7 kΩ pull-up resistor in place? Check DS18B20 wire colors. |
| CRC mismatch errors | Solder the BME280/OLED header pins. Unsoldered pins cause noise on the shared power rail. Use separate 3.3V jumpers for each sensor. |
| OLED blank | Is it wired to GPIO 21/22? Check the I2C address — some OLEDs use 0x3D instead of 0x3C. Solder the pins. |
| BME280 reads 0.0 | Likely bad connection during init — solder pins, then reboot. Make sure it's a BME280, not BMP280. |
| Wi-Fi won't connect | Check SSID/password in wifi_sta.h. ESP32 only supports 2.4 GHz networks. |
| Dashboard shows no devices | Is Mosquitto running? Is the ESP32's MQTT_BROKER_URI correct? Check with `mosquitto_sub -t "zymoscope/#"`. |
| Kasa plug not found | Run `kasa discover`. Make sure the plug is on the same Wi-Fi network. Check KASA_HEATER_HOST env var. |
| Watchdog timer errors | Normal during early boot if many sensors are initializing. Should resolve after a few seconds. |
| MQTT keeps reconnecting | Check the Mosquitto log for "already connected" errors. Make sure only one client uses the same ID. |

---

## Optional: HX711 Load Cell (Gravity Estimation)

If you want to estimate specific gravity via weight loss during fermentation,
add the HX711 + load cell kit.

### Wiring

```
HX711 pin         →   ESP32
──────────────────────────────────
VCC               →   3.3V
GND               →   GND
SCK               →   GPIO 18
DT (DOUT)         →   GPIO 19
```

Load cell to HX711: Red→E+, Black→E-, White→A+, Green→A-.

### Calibration

1. Power on — the ESP32 auto-tares on boot
2. Place a known weight on the platform (e.g., 500 ml water = ~500 g)
3. Adjust `HX711_DEFAULT_SCALE` in `firmware/main/sensor/hx711.c` if needed

---

## Optional: Relay Module (Direct Control)

If you prefer direct low-voltage DC control (fans, pumps, LED strips) instead
of smart plugs:

### Wiring

```
Relay module pin  →   ESP32
──────────────────────────────────
VCC               →   5V (VIN pin on ESP32)
GND               →   GND
IN1               →   GPIO 25  (heater control)
IN2               →   GPIO 26  (cooler control)
```

> **Note:** The relay module VCC goes to **5V/VIN**, not 3.3V. Do not connect
> mains loads to the relay screw terminals unless you know what you're doing.
> For mains loads, use the Kasa smart plug instead.

---

## What's Next

Once your prototype is running and tracking a fermentation:

- **Add more DS18B20 probes** — the firmware supports up to 4 on the same bus.
  Just wire additional probes to the same GPIO 4 + 3.3V + GND lines.
- **Run it on a Pi** — move the dashboard to a Raspberry Pi with a small
  screen for a dedicated brewing station.
- **Add a camera** — a Pi Camera Module can track krausen height and color.
  This is the planned Phase 3.

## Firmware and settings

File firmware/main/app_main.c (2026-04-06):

/*
 * Zymoscope v2 — Main application
 *
 * Wires together all subsystems:
 *   - DS18B20 temperature sensors (1-Wire, GPIO 4)
 *   - HX711 load cell ADC (GPIO 18/19)
 *   - BME280 ambient temp/humidity/pressure (I2C 0x76)
 *   - SSD1306 OLED display (I2C 0x3C)
 *   - PID temperature controller driving relays (GPIO 25/26)
 *   - Wi-Fi STA with MQTT telemetry
 *
 * Three FreeRTOS tasks:
 *   sensor_task     — reads all sensors every 5 s, updates OLED
 *   control_task    — runs PID every 5 s, drives heat/cool relays
 *   telemetry_task  — publishes MQTT JSON every 30 s
 */

#include <math.h>
#include <string.h>
#include <stdio.h>

#include "freertos/FreeRTOS.h"
#include "freertos/task.h"
#include "freertos/semphr.h"
#include "driver/gpio.h"
#include "esp_log.h"
#include "esp_mac.h"
#include "nvs_flash.h"
#include "nvs.h"

#include "sensor/ds18b20.h"
#include "sensor/hx711.h"
#include "sensor/bme280_i2c.h"
#include "display/oled.h"
#include "control/pid.h"
#include "comms/wifi_sta.h"
#include "comms/mqtt_client.h"

static const char *TAG = "zymoscope";

/* ------------------------------------------------------------------ */
/*  Relay GPIOs                                                       */
/* ------------------------------------------------------------------ */
#define RELAY_HEAT_GPIO  25
#define RELAY_COOL_GPIO  26

/* ------------------------------------------------------------------ */
/*  Shared state (protected by mutex)                                 */
/* ------------------------------------------------------------------ */
static SemaphoreHandle_t state_mutex;

static struct {
    float temps[DS18B20_MAX_SENSORS];
    int   temp_count;
    float bme_temp;
    float bme_humidity;
    float bme_pressure;
    float weight_g;
    float gravity_est;
    int   relay_heat;
    int   relay_cool;
    float setpoint;
} shared;

/* ------------------------------------------------------------------ */
/*  MQTT broker URI (compile-time default)                            */
/* ------------------------------------------------------------------ */
#ifndef MQTT_BROKER_URI
#define MQTT_BROKER_URI "mqtt://192.168.1.100:1883"
#endif

/* ------------------------------------------------------------------ */
/*  PID defaults                                                      */
/* ------------------------------------------------------------------ */
#define PID_KP  2.0f
#define PID_KI  0.1f
#define PID_KD  0.5f
#define PID_DEFAULT_SETPOINT  20.0f   /* degrees C */

/* ------------------------------------------------------------------ */
/*  Crude specific-gravity estimator from weight loss                 */
/*  Uses the idea that CO2 mass loss tracks sugar consumption.        */
/*  OG is assumed 1.050; calibrate for your wort.                     */
/* ------------------------------------------------------------------ */
static float initial_weight = 0.0f;
#define ASSUMED_OG  1.050f

static float estimate_gravity(float current_weight)
{
    if (initial_weight <= 0.0f) return ASSUMED_OG;
    float loss = initial_weight - current_weight;
    if (loss < 0.0f) loss = 0.0f;
    /* Rough: 1 g CO2 lost ≈ 0.001 SG drop per litre.
       Adjust divisor for your batch volume. */
    float sg = ASSUMED_OG - (loss / 1000.0f) * 0.001f;
    if (sg < 0.990f) sg = 0.990f;
    return sg;
}

/* ------------------------------------------------------------------ */
/*  Relay helpers                                                     */
/* ------------------------------------------------------------------ */

static void relay_init(void)
{
    gpio_config_t io = {
        .pin_bit_mask = (1ULL << RELAY_HEAT_GPIO) | (1ULL << RELAY_COOL_GPIO),
        .mode         = GPIO_MODE_OUTPUT,
        .pull_up_en   = GPIO_PULLUP_DISABLE,
        .pull_down_en = GPIO_PULLDOWN_DISABLE,
        .intr_type    = GPIO_INTR_DISABLE,
    };
    gpio_config(&io);
    gpio_set_level(RELAY_HEAT_GPIO, 0);
    gpio_set_level(RELAY_COOL_GPIO, 0);
}

/* ------------------------------------------------------------------ */
/*  sensor_task — read all sensors every 5 s                          */
/* ------------------------------------------------------------------ */

static void sensor_task(void *arg)
{
    (void)arg;
    bool first_weight = true;

    for (;;) {
        float temps[DS18B20_MAX_SENSORS];
        int   temp_count = 0;
        float bme_t = 0, bme_h = 0, bme_p = 0;
        float weight = 0;

        /* DS18B20 — read first, before any I2C activity */
        if (ds18b20_read_temps(temps, &temp_count) == ESP_OK) {
            for (int i = 0; i < temp_count; i++) {
                ESP_LOGI(TAG, "DS18B20[%d]: %.2f C", i, temps[i]);
            }
        }

        /* Brief settling delay before I2C sensors to avoid power rail noise
           coupling into the 1-Wire bus during the last read's tail */
        vTaskDelay(pdMS_TO_TICKS(50));

        /* BME280 */
        if (bme280_read(&bme_t, &bme_h, &bme_p) == ESP_OK) {
            ESP_LOGI(TAG, "BME280: %.1f C, %.1f%% RH, %.1f hPa",
                     bme_t, bme_h, bme_p);
        }

        /* HX711 */
        if (hx711_get_grams(&weight) == ESP_OK) {
            ESP_LOGI(TAG, "Weight: %.1f g", weight);
            if (first_weight && weight > 100.0f) {
                initial_weight = weight;
                first_weight = false;
                ESP_LOGI(TAG, "Initial weight captured: %.1f g", initial_weight);
            }
        }

        float sg = estimate_gravity(weight);

        /* Update shared state */
        if (xSemaphoreTake(state_mutex, pdMS_TO_TICKS(100))) {
            memcpy(shared.temps, temps, sizeof(temps));
            shared.temp_count   = temp_count;
            shared.bme_temp     = bme_t;
            shared.bme_humidity = bme_h;
            shared.bme_pressure = bme_p;
            shared.weight_g     = weight;
            shared.gravity_est  = sg;
            xSemaphoreGive(state_mutex);
        }

        /* Update OLED */
        float display_temp = (temp_count > 0) ? temps[0] : NAN;
        float sp = PID_DEFAULT_SETPOINT;
        if (xSemaphoreTake(state_mutex, pdMS_TO_TICKS(100))) {
            sp = shared.setpoint;
            xSemaphoreGive(state_mutex);
        }
        oled_show_status(display_temp, bme_t, sp,
                         shared.relay_heat, shared.relay_cool,
                         wifi_sta_is_connected());

        vTaskDelay(pdMS_TO_TICKS(5000));
    }
}

/* ------------------------------------------------------------------ */
/*  control_task — PID temperature control every 5 s                  */
/* ------------------------------------------------------------------ */

static void control_task(void *arg)
{
    (void)arg;

    /* Load setpoint from NVS (persists across reboots) */
    float initial_sp = PID_DEFAULT_SETPOINT;
    {
        nvs_handle_t nvs;
        if (nvs_open("zymoscope", NVS_READONLY, &nvs) == ESP_OK) {
            uint32_t raw;
            if (nvs_get_u32(nvs, "setpoint", &raw) == ESP_OK) {
                memcpy(&initial_sp, &raw, sizeof(float));
                ESP_LOGI(TAG, "Loaded setpoint from NVS: %.1f C", initial_sp);
            }
            nvs_close(nvs);
        }
    }

    pid_ctrl_t pid;
    pid_init(&pid, PID_KP, PID_KI, PID_KD, initial_sp);

    if (xSemaphoreTake(state_mutex, pdMS_TO_TICKS(100))) {
        shared.setpoint = initial_sp;
        xSemaphoreGive(state_mutex);
    }

    for (;;) {
        /* Check for setpoint commands from MQTT */
        float new_sp = mqtt_get_cmd_setpoint();
        if (!isnan(new_sp)) {
            pid_set_setpoint(&pid, new_sp);
            ESP_LOGI(TAG, "PID setpoint changed to %.1f C", new_sp);

            /* Persist to NVS */
            nvs_handle_t nvs;
            if (nvs_open("zymoscope", NVS_READWRITE, &nvs) == ESP_OK) {
                uint32_t raw;
                memcpy(&raw, &new_sp, sizeof(float));
                nvs_set_u32(nvs, "setpoint", raw);
                nvs_commit(nvs);
                nvs_close(nvs);
            }

            if (xSemaphoreTake(state_mutex, pdMS_TO_TICKS(100))) {
                shared.setpoint = new_sp;
                xSemaphoreGive(state_mutex);
            }
        }

        /* Get current fermentation temperature */
        float temp = 0;
        if (xSemaphoreTake(state_mutex, pdMS_TO_TICKS(100))) {
            if (shared.temp_count > 0) {
                temp = shared.temps[0];
            } else {
                temp = shared.bme_temp;
            }
            xSemaphoreGive(state_mutex);
        }

        /* Run PID */
        float output = pid_update(&pid, temp);

        /* Drive relays:
         *   output > 0.1  → heat ON,  cool OFF
         *   output < -0.1 → heat OFF, cool ON
         *   otherwise     → both OFF (deadband)
         */
        int heat = 0, cool = 0;
        if (output > 0.1f) {
            heat = 1;
        } else if (output < -0.1f) {
            cool = 1;
        }

        gpio_set_level(RELAY_HEAT_GPIO, heat);
        gpio_set_level(RELAY_COOL_GPIO, cool);

        if (xSemaphoreTake(state_mutex, pdMS_TO_TICKS(100))) {
            shared.relay_heat = heat;
            shared.relay_cool = cool;
            xSemaphoreGive(state_mutex);
        }

        ESP_LOGD(TAG, "PID: temp=%.1f sp=%.1f out=%.2f heat=%d cool=%d",
                 temp, pid.setpoint, output, heat, cool);

        vTaskDelay(pdMS_TO_TICKS(5000));
    }
}

/* ------------------------------------------------------------------ */
/*  telemetry_task — MQTT publish every 30 s                          */
/* ------------------------------------------------------------------ */

static void telemetry_task(void *arg)
{
    (void)arg;

    for (;;) {
        vTaskDelay(pdMS_TO_TICKS(30000));

        if (!mqtt_is_connected()) {
            ESP_LOGW(TAG, "MQTT not connected, skipping telemetry");
            continue;
        }

        telemetry_t telem = {0};

        if (xSemaphoreTake(state_mutex, pdMS_TO_TICKS(100))) {
            memcpy(telem.temp_c, shared.temps, sizeof(shared.temps));
            telem.temp_count    = shared.temp_count;
            telem.humidity      = shared.bme_humidity;
            telem.pressure_hpa  = shared.bme_pressure;
            telem.weight_g      = shared.weight_g;
            telem.gravity_est   = shared.gravity_est;
            telem.relay1        = shared.relay_heat;
            telem.relay2        = shared.relay_cool;
            telem.wifi_connected = wifi_sta_is_connected();
            xSemaphoreGive(state_mutex);
        }

        esp_err_t err = mqtt_publish_telemetry(&telem);
        if (err == ESP_OK) {
            ESP_LOGI(TAG, "Telemetry published");
        } else {
            ESP_LOGW(TAG, "Telemetry publish failed: %s", esp_err_to_name(err));
        }
    }
}

/* ------------------------------------------------------------------ */
/*  app_main                                                          */
/* ------------------------------------------------------------------ */

void app_main(void)
{
    ESP_LOGI(TAG, "Zymoscope v2 starting...");

    /* Print device ID (MAC-based) */
    {
        uint8_t mac[6];
        esp_read_mac(mac, ESP_MAC_WIFI_STA);
        ESP_LOGI(TAG, "Device MAC: %02X:%02X:%02X:%02X:%02X:%02X",
                 mac[0], mac[1], mac[2], mac[3], mac[4], mac[5]);
    }

    /* Create shared-state mutex */
    state_mutex = xSemaphoreCreateMutex();
    configASSERT(state_mutex);
    memset(&shared, 0, sizeof(shared));
    shared.gravity_est = ASSUMED_OG;
    shared.setpoint = PID_DEFAULT_SETPOINT;

    /* ---- Init subsystems ---- */

    /* Wi-Fi (also initialises NVS) */
    ESP_ERROR_CHECK(wifi_sta_init());

    /* I2C sensors — BME280 installs the I2C driver */
    if (bme280_init() != ESP_OK) {
        ESP_LOGW(TAG, "BME280 init failed — continuing without ambient sensor");
    }

    /* OLED (uses I2C bus set up by bme280_init) */
    if (oled_init() != ESP_OK) {
        ESP_LOGW(TAG, "OLED init failed — continuing without display");
    }

    /* DS18B20 temperature probes */
    if (ds18b20_init() != ESP_OK) {
        ESP_LOGW(TAG, "DS18B20 init failed — continuing without probes");
    }

    /* HX711 load cell */
    if (hx711_init() != ESP_OK) {
        ESP_LOGW(TAG, "HX711 init failed — continuing without scale");
    } else {
        ESP_LOGI(TAG, "Taring scale...");
        hx711_set_tare();
    }

    /* Relays */
    relay_init();

    /* MQTT (wait briefly for Wi-Fi) */
    ESP_LOGI(TAG, "Waiting for Wi-Fi before starting MQTT...");
    for (int i = 0; i < 20 && !wifi_sta_is_connected(); i++) {
        vTaskDelay(pdMS_TO_TICKS(500));
    }
    if (wifi_sta_is_connected()) {
        ESP_ERROR_CHECK(mqtt_client_init(MQTT_BROKER_URI));
    } else {
        ESP_LOGW(TAG, "Wi-Fi not connected — MQTT deferred");
        /* Could retry in telemetry_task; for now we start MQTT anyway
           and it will connect once Wi-Fi comes up. */
        mqtt_client_init(MQTT_BROKER_URI);
    }

    /* Show initial screen */
    oled_show_status(0, 0, PID_DEFAULT_SETPOINT, 0, 0, wifi_sta_is_connected());

    /* ---- Launch tasks ---- */
    xTaskCreate(sensor_task,    "sensor",    4096, NULL, 5, NULL);
    xTaskCreate(control_task,   "control",   4096, NULL, 5, NULL);
    xTaskCreate(telemetry_task, "telemetry", 4096, NULL, 4, NULL);

    ESP_LOGI(TAG, "All tasks started. Zymoscope v2 running.");
}

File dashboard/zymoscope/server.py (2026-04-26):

"""FastAPI server for the Zymoscope dashboard."""

from __future__ import annotations

import asyncio
import json
import logging
from contextlib import asynccontextmanager
from pathlib import Path
from typing import Any

from fastapi import FastAPI, WebSocket, WebSocketDisconnect, Query
from fastapi.responses import HTMLResponse
from fastapi.staticfiles import StaticFiles
from fastapi.templating import Jinja2Templates
from starlette.requests import Request

from . import db, mqtt_sub, smart_plug
from .config import settings

log = logging.getLogger(__name__)

BASE_DIR = Path(__file__).resolve().parent.parent
TEMPLATES_DIR = BASE_DIR / "templates"
STATIC_DIR = BASE_DIR / "static"

templates = Jinja2Templates(directory=str(TEMPLATES_DIR))

# Connected WebSocket clients.
_ws_clients: set[WebSocket] = set()


def _broadcast(device_id: str, payload: dict[str, Any]) -> None:
    """Called from the MQTT thread to fan-out to WebSocket clients and smart plugs."""
    loop = asyncio.get_event_loop() if False else mqtt_sub._loop
    if loop is None:
        return
    msg = json.dumps({"device_id": device_id, **payload})
    for ws in list(_ws_clients):
        asyncio.run_coroutine_threadsafe(_safe_send(ws, msg), loop)
    # Forward relay state changes to Kasa smart plugs.
    asyncio.run_coroutine_threadsafe(smart_plug.on_telemetry(device_id, payload), loop)


async def _broadcast_state(device_id: str, state: dict[str, Any]) -> None:
    """Push a shared-state update (e.g. setpoint change) to all WS clients."""
    msg = json.dumps({"type": "state", "device_id": device_id, **state})
    for ws in list(_ws_clients):
        await _safe_send(ws, msg)


async def _safe_send(ws: WebSocket, text: str) -> None:
    try:
        await ws.send_text(text)
    except Exception:
        _ws_clients.discard(ws)


# ---- Lifespan ----------------------------------------------------------------

@asynccontextmanager
async def lifespan(app: FastAPI):
    # Startup
    await db.init_db()
    mqtt_sub.set_event_loop(asyncio.get_running_loop())
    mqtt_sub.register_callback(_broadcast)
    mqtt_sub.start(daemon=True)
    # Start smart plug energy polling (every 30s) if plugs are configured.
    energy_task = None
    if settings.KASA_HEATER_HOST or settings.KASA_COOLER_HOST:
        async def _poll_energy_loop() -> None:
            while True:
                await smart_plug.poll_energy()
                await asyncio.sleep(30)
        energy_task = asyncio.create_task(_poll_energy_loop())
        log.info("Smart plug energy polling started")
    log.info("Zymoscope dashboard started")
    yield
    # Shutdown
    if energy_task:
        energy_task.cancel()
    mqtt_sub.unregister_callback(_broadcast)


app = FastAPI(title="Zymoscope", lifespan=lifespan)
app.mount("/static", StaticFiles(directory=str(STATIC_DIR)), name="static")


# ---- Routes -----------------------------------------------------------------

@app.get("/", response_class=HTMLResponse)
async def index(request: Request):
    devices = await db.get_devices()
    return templates.TemplateResponse(request, "index.html", {
        "devices": devices,
        "latest": mqtt_sub.latest,
    })


@app.get("/api/devices")
async def api_devices():
    return await db.get_devices()


@app.get("/api/telemetry/{device_id}")
async def api_telemetry(device_id: str, hours: float = Query(24)):
    return await db.get_recent_telemetry(device_id, hours)


@app.get("/api/telemetry/{device_id}/latest")
async def api_telemetry_latest(device_id: str):
    """Return the most recent stored row for a device (handy when the node is offline)."""
    row = await db.get_latest_telemetry(device_id)
    return row or {}


@app.get("/api/batches")
async def api_batches():
    return await db.get_batches()


@app.post("/api/batches")
async def api_create_batch(request: Request):
    data = await request.json()
    if not data.get("device_id"):
        return {"error": "device_id is required"}
    batch_id = await db.create_batch(data)
    return {"id": batch_id, "status": "created"}


@app.get("/api/batches/{batch_id}")
async def api_batch(batch_id: int):
    batch = await db.get_batch(batch_id)
    return batch or {}


@app.get("/api/batches/{batch_id}/telemetry")
async def api_batch_telemetry(batch_id: int):
    return await db.get_batch_telemetry(batch_id)


@app.post("/api/batches/{batch_id}/end")
async def api_end_batch(batch_id: int):
    await db.end_batch(batch_id)
    return {"status": "ended", "id": batch_id}


@app.get("/batches/{batch_id}", response_class=HTMLResponse)
async def batch_page(request: Request, batch_id: int):
    batch = await db.get_batch(batch_id)
    if not batch:
        return HTMLResponse("Batch not found", status_code=404)
    return templates.TemplateResponse(request, "batch.html", {"batch": batch})


@app.post("/api/cmd/{device_id}")
async def api_command(device_id: str, request: Request):
    data = await request.json()
    try:
        mqtt_sub.publish_command(device_id, data)
    except RuntimeError as exc:
        return {"error": str(exc)}
    # Persist & sync setpoint across dashboard clients if present in the cmd.
    if "setpoint" in data:
        try:
            sp = float(data["setpoint"])
            await db.set_setpoint(device_id, sp)
            await _broadcast_state(device_id, {"setpoint": sp})
        except (TypeError, ValueError):
            pass
    return {"status": "sent", "device_id": device_id}


@app.get("/api/state")
async def api_all_state():
    """Return shared dashboard state (setpoints, etc.) for every device."""
    return await db.get_all_device_state()


@app.get("/api/state/{device_id}")
async def api_state(device_id: str):
    """Return shared dashboard state for a single device."""
    state = await db.get_device_state(device_id)
    return state or {"device_id": device_id, "setpoint": None}


@app.post("/api/setpoint/{device_id}")
async def api_set_setpoint(device_id: str, request: Request):
    """Persist a setpoint and publish it via MQTT so every client stays in sync."""
    data = await request.json()
    try:
        sp = float(data["setpoint"])
    except (KeyError, TypeError, ValueError):
        return {"error": "missing or invalid 'setpoint'"}
    await db.set_setpoint(device_id, sp)
    try:
        mqtt_sub.publish_command(device_id, {"setpoint": sp})
    except RuntimeError as exc:
        # Even if MQTT is down, we persisted the UI value so other clients sync.
        await _broadcast_state(device_id, {"setpoint": sp})
        return {"status": "stored", "mqtt_error": str(exc), "setpoint": sp}
    await _broadcast_state(device_id, {"setpoint": sp})
    return {"status": "sent", "device_id": device_id, "setpoint": sp}
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

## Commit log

2026-03-21 Rename project
    [zymoscope-bom.csv, zymoscope.kicad_sch]
2026-03-22 Some changes to build esp32
2026-03-22 Change mouser number for DS18B20
    [zymoscope-bom.csv]
2026-04-06 Wire up prototype: DS18B20 noise fix, Kasa plug control, OLED + dashboard updates
    - Add critical sections and retry logic to DS18B20 1-Wire driver to
    handle CRC errors from power rail noise (unsoldered breadboard pins)
    - Add watchdog-safe yields during ROM search and sensor init
    - Show probe temp, ambient temp, target setpoint, and plug state on OLED
    - Persist PID setpoint in NVS (survives reboots without dashboard)
    - Fix aiosqlite double-await bug in db.py (asynccontextmanager pattern)
    - Fix Starlette TemplateResponse API change (request as first arg)
    - Fix telemetry JSON key mismatch (temps -> temp_c)
    - Add target temperature control to dashboard sidebar
    - Remove grav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
    [app_main.c, db.py, ds18b20.c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]
2026-04-12 Persist dashboard setpoint and history across clients
    The dashboard now reflects the fact that a fermentation run stretches
    across days and multiple devices (laptop, phone). Previously a refresh
    wiped the chart back to the live feed and the target temperature input
    was purely local — two phones could show different setpoints.
    - Add device_state table to store per-device setpoint; upsert on any
    /api/cmd or /api/setpoint call and broadcast the change over the
    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
2026-04-12 Show last known reading when a device is offline
    Previously if the ESP32 was disconnected the card metric tiles stayed
    on "--" even though the chart was populated from SQLite, making it
    look like no data was being shown at all. This was especially
    confusing after an overnight run that had already ended.
    - New /api/telemetry/{id}/latest endpoint returning the most recent
    stored row regardless of the current range window.
    - Dashboard seeds the temp/humidity/pressure/relay tiles from that
    row on card creation, and also from the last point of any range
    query if no live data has arrived yet.
    - Add a "last seen Xm ago" indicator in the card header that flips to
    an "offline" badge (and dim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
    [db.py, server.py]
2026-11-11 Dashboard: plug safety watchdog, retry failed plug commands
    - Retry a Kasa plug command on the next telemetry if it failed, instead of
    recording the new relay state anyway (a missed OFF could leave the heater
    on indefinitely).
    - Watchdog: switch plugs off when no telemetry arrives for
    PLUG_WATCHDOG_SEC (default 180 s), once per silence; the next telemetry
    re-asserts the relay state.
    - Stamp MQTT payloads with receive time so the WebSocket snapshot shows the
    real age of a reading instead of "0s ago".
    - Escape batch name/style/device in the sidebar list.
    - Show the firmware version reported in telemetry on the device card.
2026-11-11 Firmware: OTA updates with rollback, fail-safe control, DS18B20 recovery
    OTA:
    - Two-slot partition table for 4 MB flash (nvs kept at 0x9000/0x6000 so
    setpoint and Wi-Fi settings survive the switch) + bootloader rollback.
    - {"ota_url": ...} command on zymoscope/<id>/cmd downloads into the spare
    slot; non-"zymoscope" images are rejected. A new image is marked valid
    only after 2 min uptime and a successful telemetry publish; otherwise it
    rolls back (5 min timeout). Relays forced off before OTA reboots.
    - Retained online/offline (LWT) + OTA progress on zymoscope/<id>/status;
    telemetry carries "fw".
    - tools/ota_push.py serves the build and follows progress; docs/ota.md.
    Verified on ha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
2026-11-11 Dashboard: fast long-range charts, per-device controls, CSV export
    - /api/series: time-bucketed aggregation in SQL (avg/min/max temp, heater
    duty) capped at ~1500 points. "All" previously shipped every raw row:
    21 MB and ~150 s on the Pi for 111k rows; now ~15-75 KB.
    - Real time axis with breaks across gaps when the device was off, min/max
    band on aggregated ranges, dashed target line, heater duty in the bottom
    quarter, tooltips. Glitched probe readings are dropped from charts.
    - Device card: friendly name (rename inline), status pill (heating /
    holding / probe fault / offline) with an explanation banner, target
    control with -/+ per device, distance from target, range stats (min/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
2026-11-11 Dashboard: cache long-range series, hide duplicate device id
    Aggregating the full history takes ~2-8 s on a Pi 3 (CPU-bound; a covering
    index didn't help), so results for ranges >= 7 days are cached for 5 min.
    "All" now loads in ~0.25 s after the first request.
2026-11-11 Firmware: replace on/off-like PID with tuned time-proportioned control
    The old loop (Kp 2, Ki 0.1, Kd 0.5 per 5 s step, thresholded at ±0.1)
    behaved like a ±0.5 °C hysteresis thermostat; with heat-mat lag that gave
    a ±1.1 °C limit cycle (~21 min period) around the setpoint.
    - PID in physical units with explicit dt: Kp 0.15/°C, Ti 1200 s, Td 60 s
    - Derivative on filtered measurement; conditional integration (no windup)
    - Time-proportioned output: 420 s window, 60 s minimum pulse
    - Relay changes trigger an immediate telemetry publish so the Kasa plug
    follows within ~1 s instead of up to 30 s
    - Integral persisted in NVS (pid_i) and restored near setpoint after a
    reboot/OTA, avoiding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
2026-11-11 Dashboard: temperature-control stats for batches
    When a batch ends, compute how well the temperature was held over its
    hold phase (warm-up and the first 60 min after reaching target excluded):
    average offset, 90% spread, % of time within ±0.5 °C, overshoot while
    settling, and heater cycles per hour. Shown on the batch page (live "so
    far" while running) and as a one-line summary in the batch list.
    - setpoint_log table records every target change (seeded from the
    current setpoint), so stats follow mid-batch setpoint changes
    - batches.target lets older batches, from before setpoints were logged,
    be scored against a manually entered target
    - batches.stats keeps the result saved at end
    - G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
2026-11-11 Firmware: OLED pages, easter eggs, batch strip, setpoint in telemetry
    - Display split into oled.c (I2C only), gfx.c (drawing, 8x8 + 3x5 fonts,
    seven-segment digits), ui.c (pure page layouts) and display.c (task,
    4 h history, page state). Main page: big temperature, target, heater
    on-time bar, 4 h trend; chart and info pages; cat and yeast easter eggs.
    - New MQTT cmds: {"display": next|main|chart|info|pet} and
    {"batch_name", "batch_elapsed"} for the status strip.
    - Display frames wait on a 1-Wire quiet mutex (held across the DS18B20
    read and its 50 ms settle) so I2C never overlaps a 1-Wire read.
    - Burn-in: picture orbits by 1 px every 5 min.
    - Telemetry carries the active setpoint a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
2026-11-11 Dashboard: device-reported target history, OLED controls, batch push
    - setpoint_log is written from telemetry for devices that report their
    setpoint (what the device ran, when), else from the command path.
    Shared UI target follows the device after a 90 s grace period.
    - Setpoint validated to 0-60 C on /api/setpoint and /api/cmd.
    - Subscribe to zymoscope/+/status, routed apart from telemetry (never
    stored, never feeds the plug watchdog); on "online", and on batch
    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
2026-11-11 Dashboard: phone alerts via self-hosted ntfy
    One notification when a condition starts and one when it clears:
    offline / back online, probe fault / probe OK, target reached, and out
    of range (more than 3 °C from the target for 15 min after reaching it)
    / back in range. State machine per device in zymoscope/alerts.py, fed
    from telemetry plus a 30 s offline check; devices already silent at
    startup aren't re-reported. Configured with NTFY_URL / NTFY_TOPIC
    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
